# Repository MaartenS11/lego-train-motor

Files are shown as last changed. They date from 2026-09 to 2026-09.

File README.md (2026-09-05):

# Lego compatible train motor
OpenSCAD models for 3D-printable, LEGO-compatible train parts:
train wheels and a motor frame. The motor itself uses a TT motor which can be bought online easily.

## Train wheel
`trainwheel.scad` models the wheel that ships on the 9V/PF LEGO train motor
("Train Wheel RC, Spoked with Technic Axle Hole and Rubber Friction Band",
[BrickLink 55423c01](https://www.bricklink.com/v2/catalog/catalogitem.page?P=55423c01)).

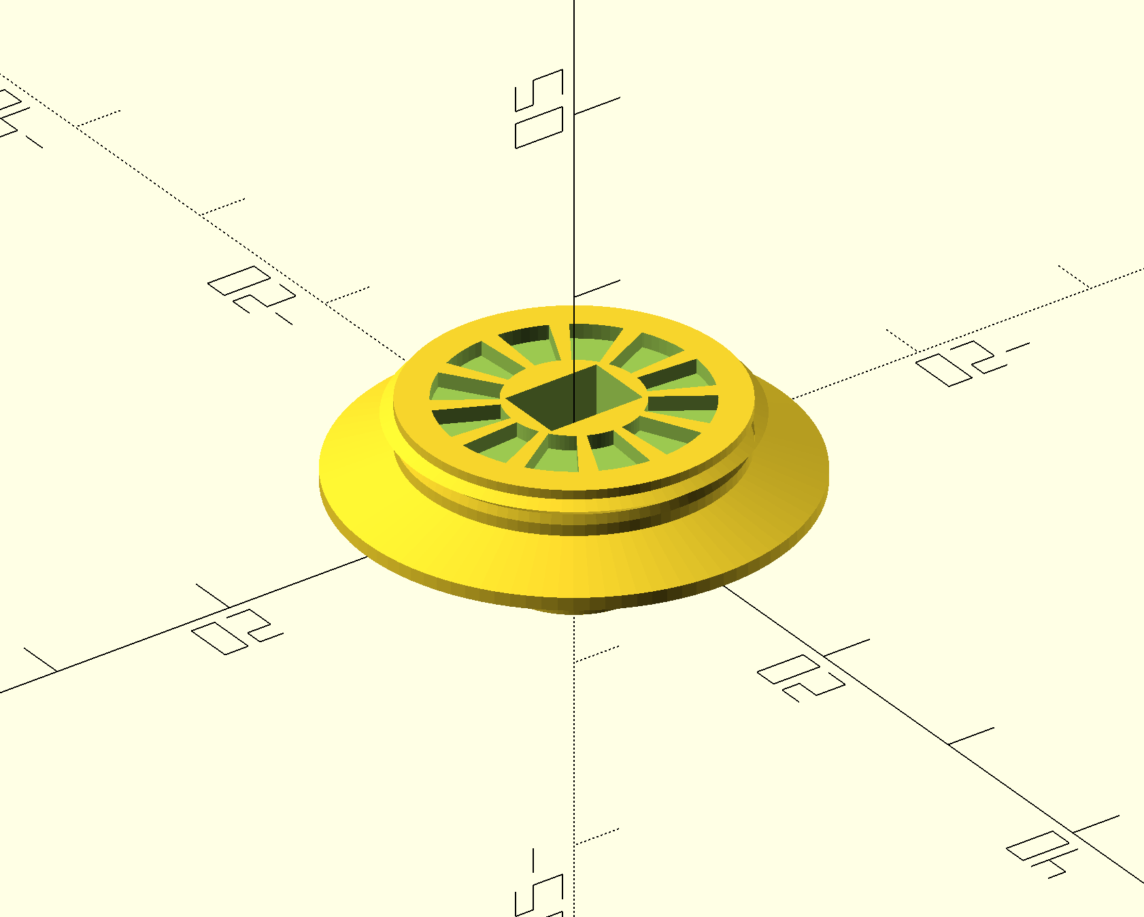
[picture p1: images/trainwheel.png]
Train wheel render


## Motor frame
`frame.scad` models a frame that goes around a TT motor, resulting in a LEGO-compatible train motor. The front axle is the TT motor's own axle, onto which you attach two train wheels. At the back there is a hole in which you put a regular LEGO axle and some train wheels. If you don't currently have any train wheels, or need more, you can print `trainwheel.scad` with the regular LEGO axle option enabled.

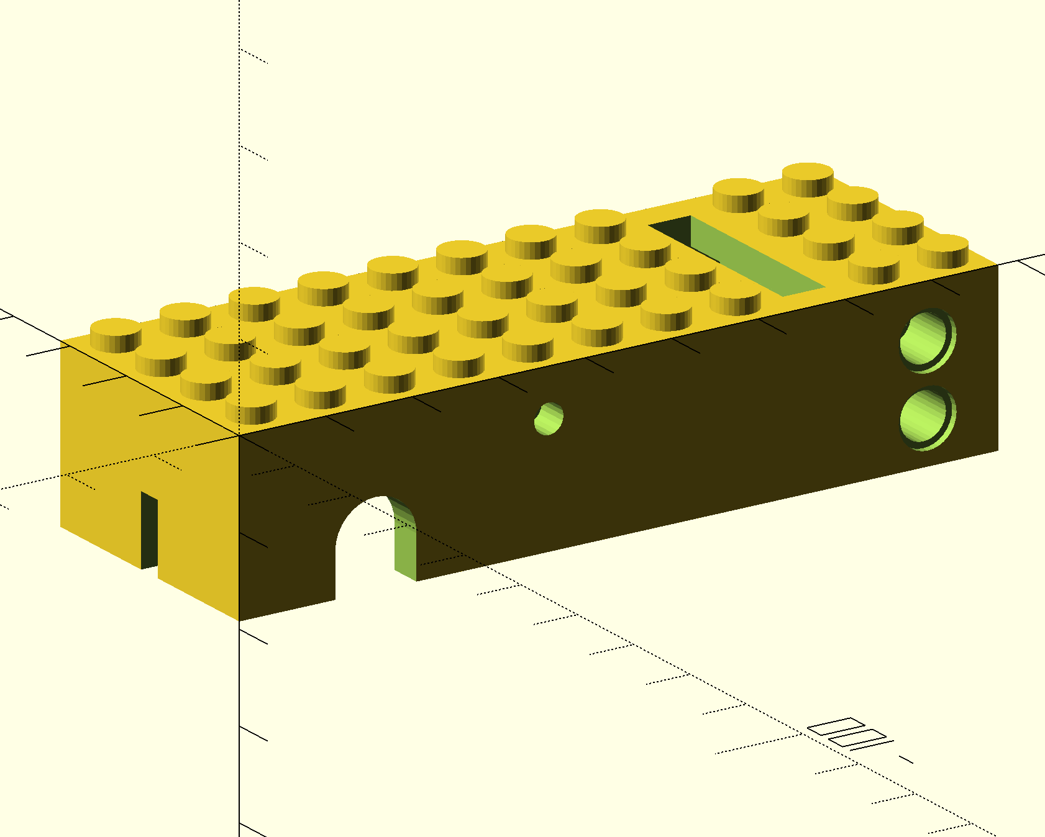
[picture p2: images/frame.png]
Frame render


## Result
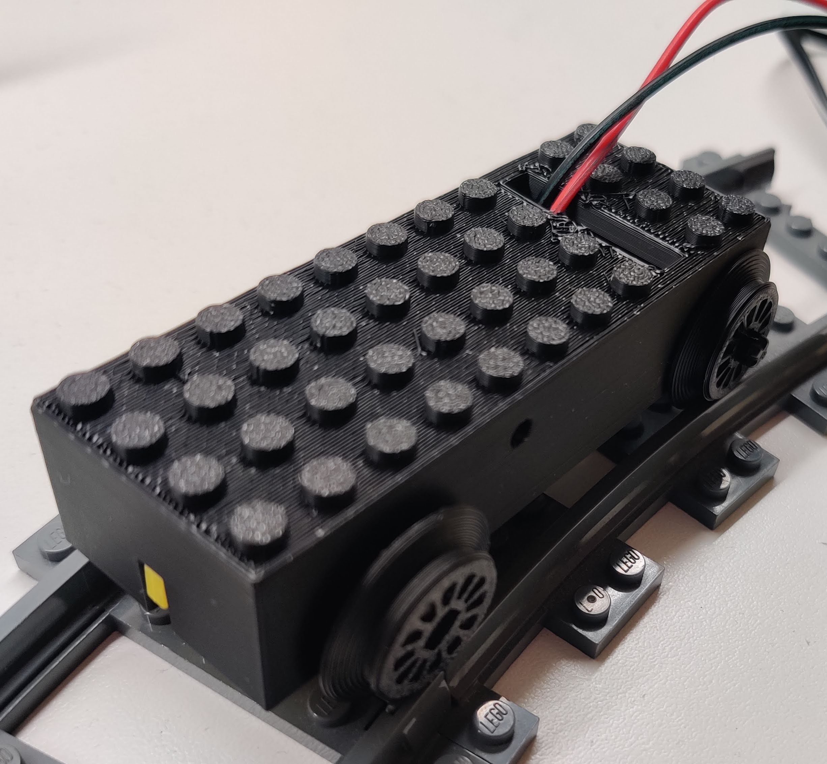
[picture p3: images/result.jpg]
Result


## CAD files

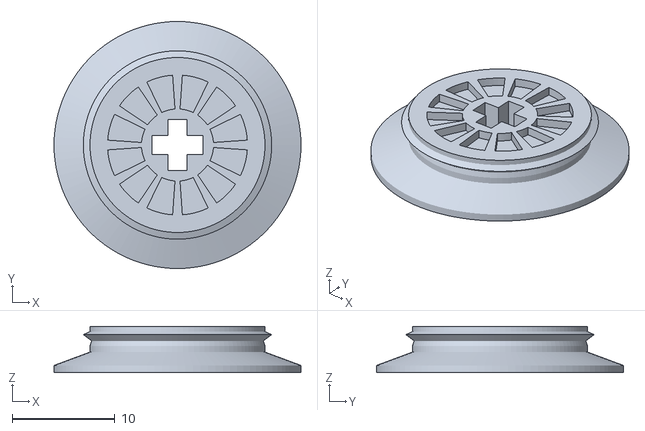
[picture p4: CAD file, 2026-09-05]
trainwheel.stl
24.0 x 24.0 x 4.50

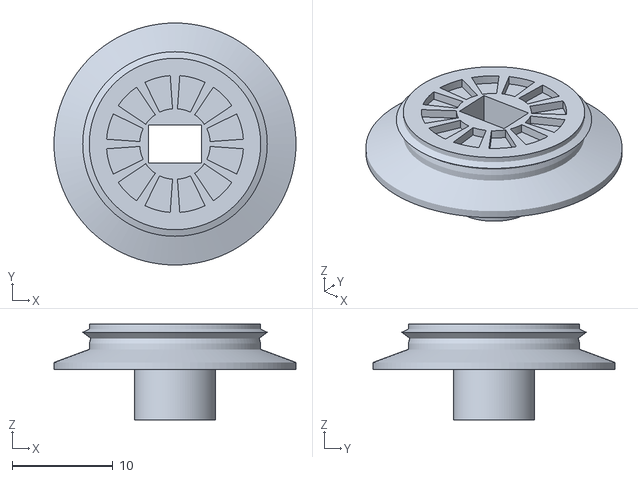
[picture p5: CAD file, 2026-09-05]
trainwheel_tt.stl
24.0 x 24.0 x 9.50

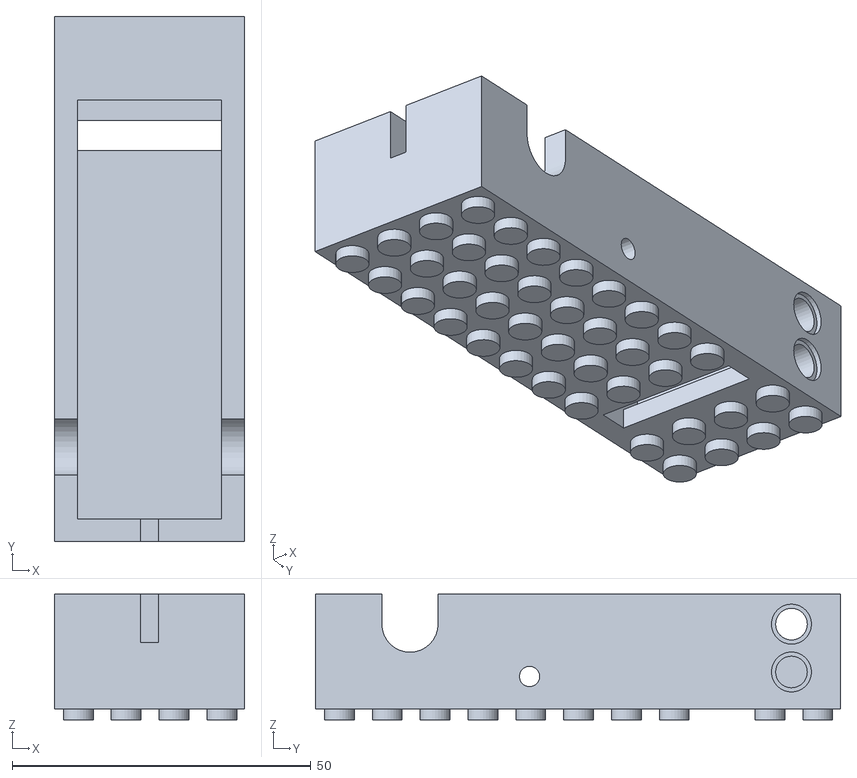
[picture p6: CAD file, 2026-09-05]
frame.stl
31.8 x 87.8 x 21.0

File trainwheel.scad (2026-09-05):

// This trainwheel was unlike the motor frame mostly generated using CLAUDE + manual edits.
// Parametric LEGO Train Wheel, modeled after the official wheel that ships
// on the 9V/PF train motor: "Train Wheel for RC Train w Technic Axle Hole
// and Rubber Ring" (BrickLink 55423c01 / LDraw u9241+u9242).
// Profile (flange/riser/tread diameters, axle hole shape) measured directly
// off a reference scan of the real part (55423.stl): wide tapered flange,
// stepped riser, crowned+grooved tread, 12-spoke closed hub face.
// All measurements in millimeters (mm)

lego_axle = false;

// Resolution
$fn = 100;

// Overall depth
wheel_width = 4.5;

// Flange: a short straight full-diameter rim edge (like the real part's
// rail-contact edge), then a shallow cone down to the riser
flange_dia            = 24.0;
flange_straight_height = 0.7;  // straight section at full flange_dia, from z=0
flange_height          = 2.0;  // total flange section height (straight + taper)

// Riser: cylindrical shoulder between flange and tread
riser_dia    = 17.0;
riser_height = 0.6;

// Tread: crowned profile with a dip (rubber-band groove) near the riser
// side and a slight crown bulge further out, tapering back in at the top
tread_height    = 1.4;
groove_dia      = 16.7;
groove_z_frac   = 0.35;  // fraction of tread_height where the groove sits
crown_dia       = 18.3;
crown_z_frac    = 0.78;  // fraction of tread_height where the crown peak sits
tread_end_dia   = 17.0;

// Hub face (closed disc with recessed spoke channel — only the axle hole
// goes all the way through)
//hub_dia       = 6.0;    // inner boundary of the recessed channel
hub_dia       = 7.0;    // inner boundary of the recessed channel
hub_rim_wall  = 1.5;    // solid wall width left at the outer rim
spoke_count   = 12;     // matches the real part
spoke_rib_deg = 8;      // angular width of each raised spoke rib
pocket_floor  = -0.3;    // material left at the bottom of the recessed channel

// Technic cross-axle hole (fits the train motor's output shaft), measured
// off the reference part: ~5.2mm tip-to-tip, ~2.2mm arm width
axle_span = 4.96;
axle_arm  = 1.84;  // adjust both for your printer tolerance

eps = 0.05;  // overlap between stacked solids, avoids coplanar z-fighting

riser_end_z = flange_height + riser_height;
tread_end_z = riser_end_z + tread_height;
hub_section_height = wheel_width - tread_end_z;
rim_ring_dia = tread_end_dia;
channel_outer_dia = rim_ring_dia - 2 * hub_rim_wall;

extender_height = 5;

module axle_hole() {
    if (lego_axle) {
        h = wheel_width + 2;
        for (a = [0, 90])
            rotate([0, 0, a])
                translate([-axle_span / 2, -axle_arm / 2, -1])
                    cube([axle_span, axle_arm, h]);
    }
    else {
        // tt motor axle
        h = wheel_width + 2 + extender_height;
        axle_heigth = 3.7 + 0.02; // 0.02 tolerance
        axle_width = 5.3;
        translate([-axle_width / 2, -axle_heigth / 2, -1 - extender_height])
            cube([axle_width, axle_heigth, h]);
    }
}

function wedge_pts(a0, span, r, steps = 8) =
    concat([[0, 0]], [for (i = [0 : steps]) [r * cos(a0 + span * i / steps), r * sin(a0 + span * i / steps)]]);

module pocket_2d(r_in, r_out, a0, span) {
    intersection() {
        difference() {
            circle(r = r_out);
            circle(r = r_in);
        }
        polygon(wedge_pts(a0, span, r_out + 1));
    }
}

// Blind recesses cut into the hub face between the spoke ribs — visual
// detail only, never breaking through to the flange side.
module spoke_pockets() {
    // clamp so at least 0.1mm of floor always remains, even if pocket_floor
    // is larger than the currently configured hub_section_height
    effective_floor = min(pocket_floor, hub_section_height - 0.1);
    depth = hub_section_height - effective_floor;
    pocket_span = 360 / spoke_count - spoke_rib_deg;
    for (i = [0 : spoke_count - 1]) {
        a0 = i * 360 / spoke_count + spoke_rib_deg / 2;
        // cut down from the true outward face (wheel_width), not from
        // tread_end_z, so this stays correct even if flange/riser/tread
        // heights change and shrink or grow hub_section_height
        translate([0, 0, wheel_width - depth])
            linear_extrude(height = depth + 0.5)
                // outer radius stops just short of the disc's own edge
                // so the cut doesn't sit exactly on the model's real outer surface
                pocket_2d(hub_dia / 2, channel_outer_dia / 2 - 0.2, a0, pocket_span);
    }
}

// Axisymmetric flange + riser + crowned/grooved tread body
module wheel_body() {
    profile = [
        [0, 0],
        [flange_dia / 2, 0],
        [flange_dia / 2, flange_straight_height],
        [riser_dia / 2, flange_height],
        [riser_dia / 2, riser_end_z],
        [groove_dia / 2, riser_end_z + tread_height * groove_z_frac],
        [crown_dia / 2, riser_end_z + tread_height * crown_z_frac],
        [tread_end_dia / 2, tread_end_z],
        [0, tread_end_z],
    ];
    rotate_extrude()
        polygon(profile);
}

module lego_train_wheel() {
    difference() {
        union() {
            wheel_body();

            // Closed hub face — solid disc, overlapped into the tread body
            translate([0, 0, tread_end_z - eps])
                cylinder(d = rim_ring_dia, h = hub_section_height + eps);
            
            if (!lego_axle)
            translate([0, 0, -extender_height])
                cylinder(extender_height, 4, 4);
        }

        axle_hole();
        spoke_pockets();
    }
}

lego_train_wheel();

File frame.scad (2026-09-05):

lego_block_height = 9.6;
lego_stud_spacing = 8.0;
lego_plate_heigth = 3.2;
lego_stud_dia = 4.8 + 0.2;
lego_stud_height = 1.8;
function lego_block_size(size) = size * lego_stud_spacing - 0.2;

// Grid of LEGO studs on an 8mm pitch, sized nx x ny studs, hanging below
// z=0 (overlapping it by eps) so it unions cleanly onto the bottom face
// of a block that starts at z=0.
module lego_stud_grid(nx, ny) {
    for (ix = [0 : nx - 1])
        for (iy = [0 : ny - 1])
            translate([ix * lego_stud_spacing + lego_stud_spacing / 2,
                        iy * lego_stud_spacing + lego_stud_spacing / 2,
                        -lego_stud_height + eps])
                cylinder(h = lego_stud_height, d = lego_stud_dia, $fn = 30);
}

lego_hole_tolerance = 0.25;

module lego_hole() {
    translate([7.8, 0, 0])
    rotate([0,-90,0]) 
    //cylinder(8, 2.4, 2.4, $fn=20);
    cylinder(8, 2.4 + lego_hole_tolerance, 2.4 + lego_hole_tolerance, $fn=32);
    
    translate([0.8, 0, 0])
    rotate([0,-90,0]) 
    //cylinder(1, 3.1, 3.1, $fn=20);
    cylinder(1, 3.1 + lego_hole_tolerance, 3.1 + lego_hole_tolerance, $fn=32);
    
    translate([7.8, 0, 0])
    rotate([0,-90,0]) 
    //cylinder(1, 3.1, 3.1, $fn=20);
    cylinder(0.8, 3.1 + lego_hole_tolerance, 3.1 + lego_hole_tolerance, $fn=32);
};

module lego_hole_long(hole_length) {
    translate([hole_length, 0, 0])
    rotate([0,-90,0]) 
    //cylinder(8, 2.4, 2.4, $fn=20);
    cylinder(hole_length, 2.4 + lego_hole_tolerance, 2.4 + lego_hole_tolerance, $fn=32);
    
    translate([0.8, 0, 0])
    rotate([0,-90,0]) 
    //cylinder(1, 3.1, 3.1, $fn=20);
    cylinder(1, 3.1 + lego_hole_tolerance, 3.1 + lego_hole_tolerance, $fn=32);
};

motor_width = 24; // trying to give it some space but also not too much
motor_heigth = 22.44;
wire_spacing = 3;
motor_length = 65 + 1 + wire_spacing;
motor_wire_gap = 5;
axle_offset = 11;

motor_start_offset = 7 - 2.2; // So the holes align with the lego studs
motor_start_extra_space = 1;
eps = 0.01;
tolerance = 0.2;

difference() {
    case_width = lego_block_size(4);
    case_height = lego_block_height * 2;

    union() {
        cube([case_width, lego_block_size(11), case_height]);
        
        // studs
        lego_stud_grid(4, 8);
        translate([0,lego_stud_spacing*9,0])
        lego_stud_grid(4, 2);
    }

    // Thing sticking out at the front of the motor
    front_stick_length = 5 + 1 + tolerance; // 1 mm of extra spacing so the motor can slide a little forward if needed
    translate([case_width/2-3/2,motor_start_offset-front_stick_length+eps,lego_plate_heigth + axle_offset - front_stick_length/2])
    cube([3, front_stick_length, case_height]);
    
    // Motor itself
    translate([case_width/2-motor_width/2,motor_start_offset-motor_start_extra_space,lego_plate_heigth])
    cube([motor_width,motor_length+motor_start_extra_space,case_height]);
    
    // Wire hole
    translate([case_width/2-motor_width/2,motor_start_offset + motor_length-motor_wire_gap-3.4,-eps])
    cube([motor_width,motor_wire_gap,lego_plate_heigth+eps*2]);
    
    // Motor axle hole
    hole_r = 4 + 0.5 + tolerance;
    translate([case_width + 1,motor_start_offset + axle_offset,lego_plate_heigth + axle_offset]) {
        rotate([0, -90, 0])
        cylinder(case_width + 2, hole_r, hole_r, $fn=32);
    }
    translate([-1, motor_start_offset + axle_offset - hole_r,lego_plate_heigth + axle_offset])
    cube([case_width + 2, hole_r * 2, case_height]);
    
    // Motor mounting holes
    translate([case_width + 1,motor_start_offset + axle_offset + 20,lego_plate_heigth + axle_offset - 8.75])
    rotate([0, -90, 0])
    cylinder(case_width + 2, 1.5 + tolerance, 1.5 + tolerance, $fn=20);
    
    // Bottom mounting holes
    /*translate([case_width + 1,motor_start_offset + axle_offset + 20,lego_plate_heigth + axle_offset + 8.75])
    rotate([0, -90, 0])
    cylinder(case_width + 2, 1.5 + tolerance, 1.5 + tolerance, $fn=20);*/
    
    // Lego axle + extra technic hole
    translate([0,motor_start_offset + axle_offset + lego_block_size(8),lego_plate_heigth + axle_offset]) {
        lego_hole_long(case_width/2+eps);
        
        translate([case_width,0,0])
        rotate([0,0,180])
        lego_hole_long(case_width/2+eps);
        
        translate([0,0,-lego_stud_spacing]) {
            lego_hole();
            
            translate([case_width,0,0])
            rotate([0,0,180])
            lego_hole();
        }            
    }
}

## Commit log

2026-09-04 Added WIP motor frame
    [frame.scad, frame.stl]
2026-09-04 Add more tolerance + skirt design
    [frame.scad, frame.stl]
2026-09-04 Move holes to align with studs + move wire hole
    Downside is that the motor now has a tiny 0.2 mm
    yellow part sticking out in the front. Now this
    does not matter so much as the motor is usually
    under a train with things in front of it so it is
    probably worth having the holes be aligned on the
    lego grid.
    [frame.scad, frame.stl]
2026-09-04 Slightly increase stud size
    The printed version measured around 4.6mm for the
    studs while there was 4.8 in the file so I
    increased with 0.2 so that 5 will result in 4.8
    physically, will see how that goes.
    [frame.scad, frame.stl]
2026-09-04 Make trainwheel.scad switch between lego and tt motor axles with a boolean
    [trainwheel.scad]
2026-09-05 Moved mount hole very slightly + add 1mm of padding for the front of the motor + slightly less tolerance on the lego holes + slightly longer skirt (2,5 lego blocks)
    This should allow the motor to slide a little forward if need be if needed for
    the mounting hole.
    [frame.scad, frame.stl]
2026-09-05 Extend skirt a little more to cover the full motor + add bottom mounting hole + reduce the estimated motor width to be a little tighter
    [frame.scad, frame.stl]
2026-09-05 Add an extra technic hole
    [frame.scad, frame.stl]
2026-09-05 Update lego axle dimensions for the trainwheels
    [trainwheel.scad]
2026-09-05 Remove extra technic hole and add a slight bit of ground clearance by reducing the skirt length
    [frame.scad, frame.stl]
2026-09-05 Reduce skirt length again due to ground clearance concerns
    Even more concerning if you consider track switches which might not work with
    the current design.
    [frame.scad, frame.stl]
2026-09-05 Reduce motor axle hole size
    Previously it had 2mm of extra spacing, now only 1mm.
    [frame.scad, frame.stl]
2026-09-05 Added trainwheel stl files
    [trainwheel.scad, trainwheel.stl, trainwheel_tt.stl]
